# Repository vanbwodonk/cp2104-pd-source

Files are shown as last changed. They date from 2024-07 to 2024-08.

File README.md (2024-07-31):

# CP2104 USB Serial with PD source

This project is the result of research for 2 things, USB serial data for Android devices and being able to charge using a valid PD protocol. Common Type-C cables include two types: dual-head Type-C interface (full function) and Type-A to Type-C interface. The dual-head Type-C interface cable is too expensive and has limited usage scenarios, so Type-A to Type-C cable still has a large market. Type-A to Type-C cables are divided into two types: charging only and charging and data transmission. This project introduces a cable that can both charge and transmit serial data using the LDR6023SS USB PD communication chip from Lederer . It is simple in design and low in cost.

### Main functions of LDR6023:

1. Support USB PD 2.0, compatible with USB PD 3.0.
2. Support two USB-C DRP ports.
3. Support transparent transmission of PDO and REQUEST negotiation between the adapter and the smart device.
4. Automatically switch between DR_SWAP and UFP modes.

### Example simple schematic:

Since it is applied to wires, the chip package should be as small as possible. The smallest package of the LDR6023 series is SSOP-16, and the specific model is LDR6023SS. The schematic diagram is shown below:

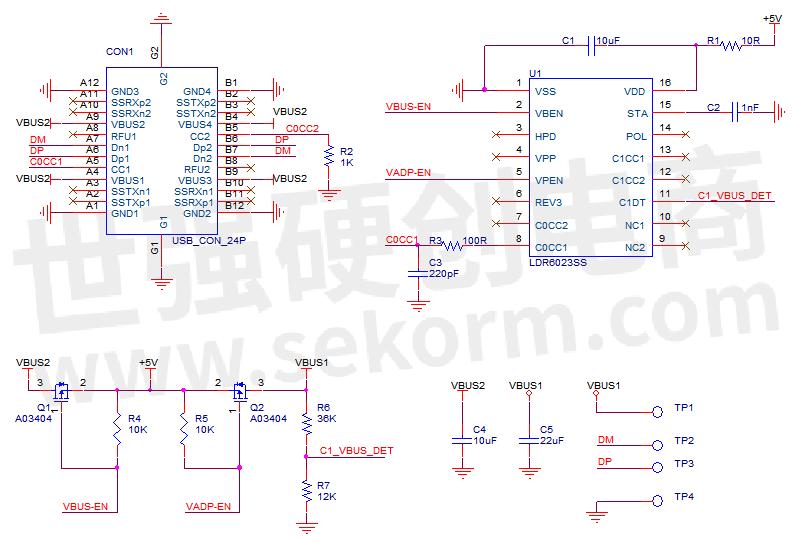
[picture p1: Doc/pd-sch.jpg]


### Link:

I found all this documentation from chinnese web. Please use google translate or somehing: 

1. https://www.sekorm.com/news/76945168.html

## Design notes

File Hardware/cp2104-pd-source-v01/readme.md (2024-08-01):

### Easyeda2kicad

Pull LDR6023C library from Easyeda with python library easyeda2kicad. Run terminal inside kicad project folder, then run this command

```bash
easyeda2kicad --lcsc_id C2919628 --full --overwrite --output ./easyeda2kicad/easyeda2kicad --project-relative
```

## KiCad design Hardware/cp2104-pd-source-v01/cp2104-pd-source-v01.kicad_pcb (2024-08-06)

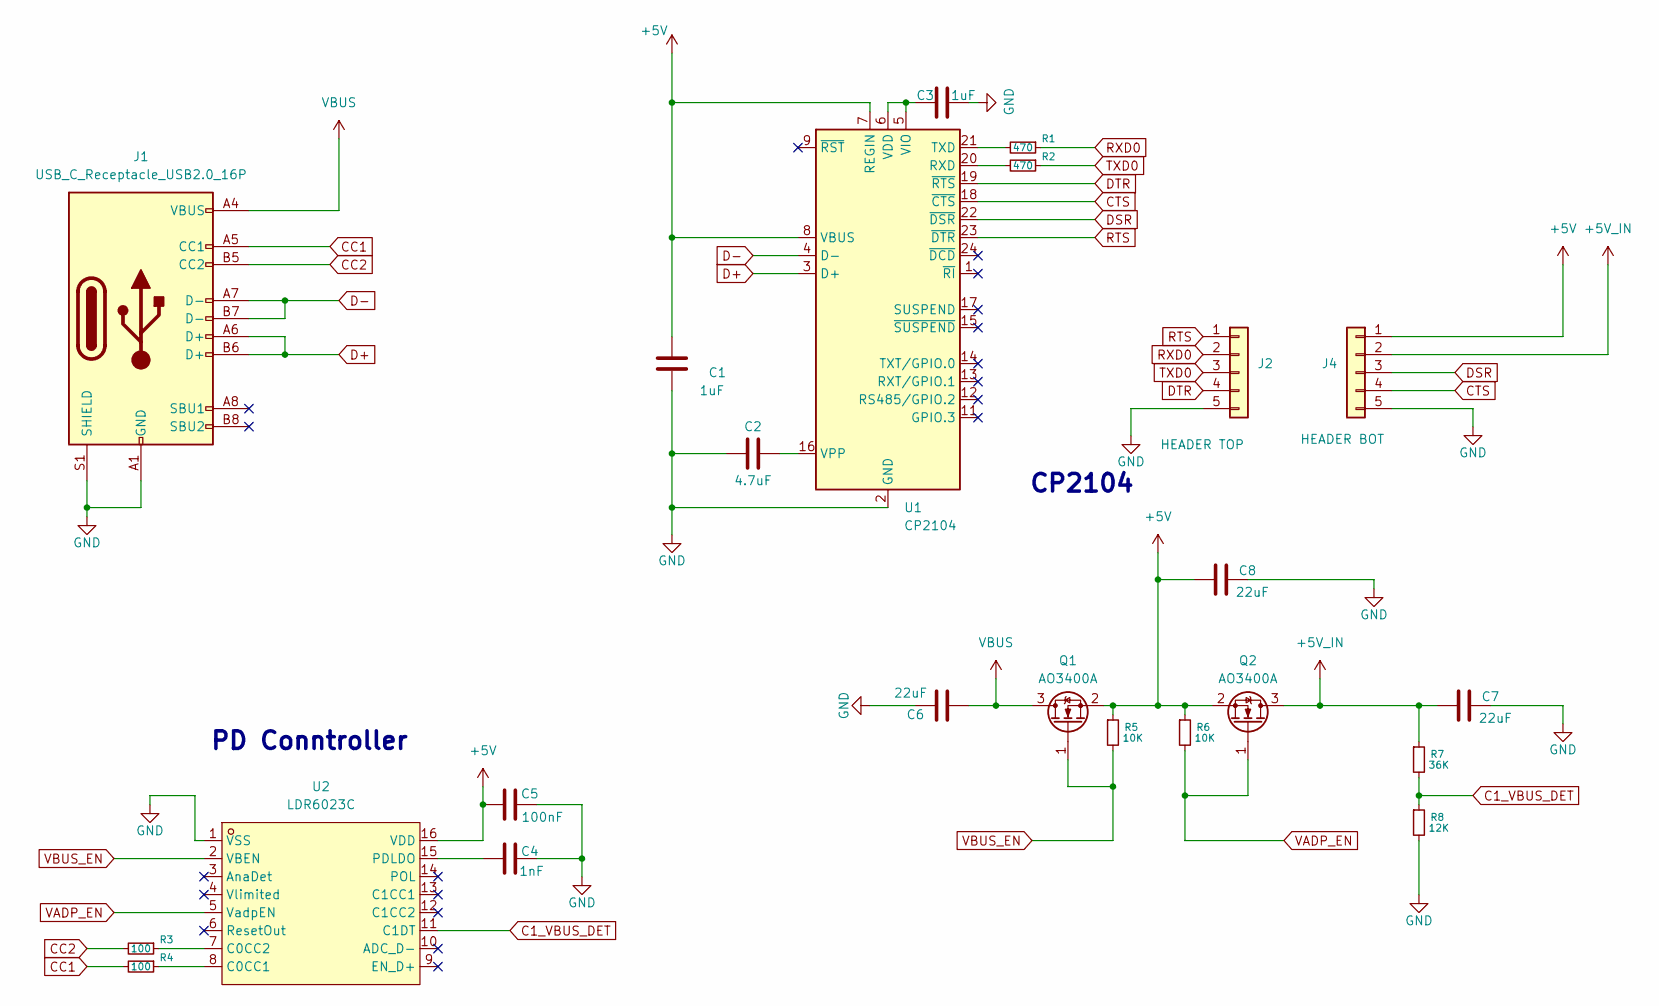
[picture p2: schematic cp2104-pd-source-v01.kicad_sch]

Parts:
C1, C3: 1uF; C_0603_1608Metric; JLCPCB Part # C15849
C2: 4.7uF; C_0603_1608Metric; JLCPCB Part # C19666
C4: 1nF; C_0603_1608Metric
C5: 100nF; C_0603_1608Metric
C6, C7, C8: 22uF; C_1206_3216Metric; JLCPCB Part # C15849
J1: USB_C_Receptacle_USB2.0_16P; USB_C_Receptacle_GCT_USB4105-xx-A_16P_TopMnt_Horizontal
J2: HEADER TOP; Harwin_M20-89005xx_1x05_P2.54mm_Horizontal
J4: HEADER BOT; Harwin_M20-89005xx_1x05_P2.54mm_Horizontal
Q1, Q2: AO3400A; SOT-23
R1, R2: 470; R_0603_1608Metric; JLCPCB Part # C23179
R3, R4: 100; R_0603_1608Metric; JLCPCB Part # C23179
R5, R6: 10K; R_0603_1608Metric; JLCPCB Part # C23179
R7: 36K; R_0603_1608Metric; JLCPCB Part # C23179
R8: 12K; R_0603_1608Metric; JLCPCB Part # C23179
U1: CP2104; QFN-24-1EP_4x4mm_P0.5mm_EP2.6x2.6mm; JLCPCB Part # C47742
U2: LDR6023C; SSOP-16_L5.0-W4.4-P0.65-LS6.4-BL; LCSC Part C2919628

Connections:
+5V: C1.1, C5.1, C8.1, J4.1, Q1.2 (S), Q2.2 (S), R5.1, R6.1, U1.7 (REGIN), U1.8 (VBUS), U2.16 (VDD)
+5V_IN: C7.1, J4.2, Q2.3 (D), R7.1
C1_VBUS_DET: R7.2, R8.1, U2.11 (C1DT)
CC1: J1.A5 (CC1), R4.2
CC2: J1.B5 (CC2), R3.2
CTS: J4.4, U1.18 (~CTS)
D+: J1.A6 (D+), J1.B6 (D+), U1.3 (D+)
D-: J1.A7 (D-), J1.B7 (D-), U1.4 (D-)
DSR: J4.3, U1.22 (~DSR)
DTR: J2.4, U1.19 (~RTS)
GND: C1.2, C2.2, C3.2, C4.2, C5.2, C6.2, C7.2, C8.2, J1.A1 (GND), J1.A12 (GND), J1.B1 (GND), J1.B12 (GND), J1.S1 (SHIELD), J2.5, J4.5, R8.2, U1.2 (GND), U1.25 (GND), U2.1 (VSS)
unnamed: R2.2, U1.20 (RXD)
unnamed: R1.2, U1.21 (TXD)
unnamed: C3.1, U1.5 (VIO), U1.6 (VDD)
unnamed: C2.1, U1.16 (VPP)
unnamed: R4.1, U2.8 (C0CC1)
unnamed: R3.1, U2.7 (C0CC2)
unnamed: C4.1, U2.15 (PDLDO)
RTS: J2.1, U1.23 (~DTR)
RXD0: J2.2, R1.1
TXD0: J2.3, R2.1
VADP_EN: Q2.1 (G), R6.2, U2.5 (VadpEN)
VBUS: C6.1, J1.A4 (VBUS), J1.A9 (VBUS), J1.B4 (VBUS), J1.B9 (VBUS), Q1.3 (D)
VBUS_EN: Q1.1 (G), R5.2, U2.2 (VBEN)

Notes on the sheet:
CP2104
PD Conntroller

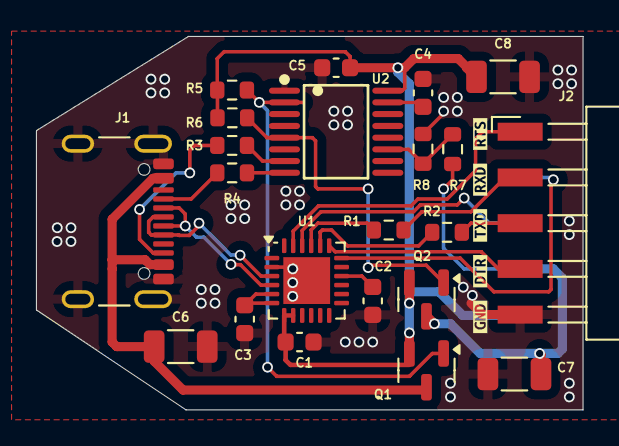
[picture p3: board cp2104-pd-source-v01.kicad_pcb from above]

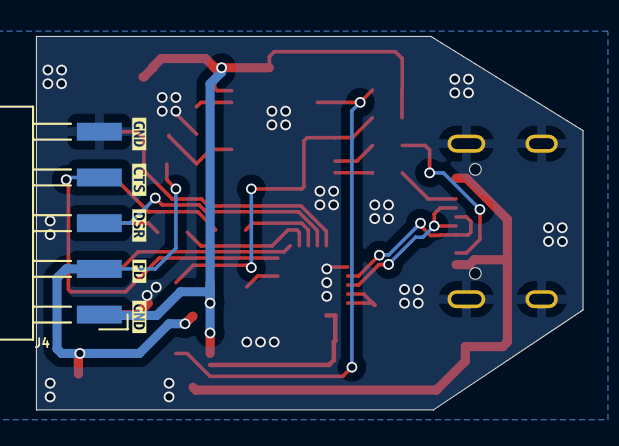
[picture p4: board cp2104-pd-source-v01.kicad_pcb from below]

Board: 2 copper layers, 30.4 x 20.7 mm, 33 parts (6 on the bottom side), 24 nets.

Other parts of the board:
kibuzzard-66B1E9B1: G***; kibuzzard-66B1E9B1
kibuzzard-66B1E9B7: G***; kibuzzard-66B1E9B7
kibuzzard-66B1E9BE: G***; kibuzzard-66B1E9BE
kibuzzard-66B1E90B: G***; kibuzzard-66B1E90B
kibuzzard-66B1E91A: G***; kibuzzard-66B1E91A
kibuzzard-66B1E901: G***; kibuzzard-66B1E901
kibuzzard-66B1E950, kibuzzard-66B1E950#2: G***; kibuzzard-66B1E950
kibuzzard-66B1E959: G***; kibuzzard-66B1E959
kibuzzard-66B1E998: G***; kibuzzard-66B1E998

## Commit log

2024-08-01 try easyeda2kicad to local lib
    [cp2104-pd-source-v01.kicad_pcb, cp2104-pd-source-v01.kicad_sch]
2024-08-06 add final pcb
    [cp2104-pd-source-v01.kicad_pcb, cp2104-pd-source-v01.kicad_sch]
2024-08-06 add jlcpcb production files
    [cp2104-pd-source-v01-CuBottom.gbr, cp2104-pd-source-v01-CuTop.gbr, cp2104-pd-source-v01-EdgeCuts.gbr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]
2024-08-06 exclude some component from bom
    [cp2104-pd-source-v01.kicad_pcb]
